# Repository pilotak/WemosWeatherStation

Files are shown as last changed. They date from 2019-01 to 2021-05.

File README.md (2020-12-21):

# Wemos weather station
 


An all-in-one ESP8266 based weather station. Hardware configuration is split into two parts due to easier maintenance in case of ESP8266 failure and fuse replacement (the board outside is protected against lighting). FW can easily be compiled by PlatformIO or Arduino IDE if necessary, otherwise can be downloaded in **Releases**.

Data are sent over MQTT where [Telegraf](https://www.influxdata.com/time-series-platform/telegraf/) is waiting to push data to [InfluxDB](https://www.influxdata.com/time-series-platform/influxdb/) and [Grafana](https://grafana.com/) tool to render charts.

**Main futures:**
- Easy configuration via [WiFiManager](https://github.com/tzapu/WiFiManager)
- WeMos based shield
- WH1080 mechanical components for rain, wind measurements and radiation shield
- MCP9808: high precision temperature sensor
- HTU21D or SHT31D: humidity sensor
- BMP280 or LPS35HW: pressure sensor
- Output data is via MQTT
- supports Arduino OTA, HTTP OTA and [NoFuss OTA](https://github.com/xoseperez/espurna)

*Note: on the board there can be only one humidity sensor, one pressure sensor and one temperature sensor in any combination, please see `platformio.ini`*

## Wemos-meteo shield
Based on my libraries:
- [WeatherMeters](https://github.com/pilotak/WeatherMeters)
- [MeteoFunctions](https://github.com/pilotak/MeteoFunctions)

### MQTT topics:
#### `name/status`
If online:
`sensors` key: binary map of sensors state (OK=1, failure=0)
```json
{
  "status": 1,
  "ip": "192.168.1.7",
  "rssi": -10,
  "sensors": 7,
  "fw_ver": "1.0.0"
}
```

otherwise:
```json
{
  "status": 0
}
```

#### `name/sensors`
If any of the value can't be calculated, it sends `NaN`
```json
{
  "humidity_rel": 79.84,
  "humidity_abs": 14.93,
  "pressure_rel": 1021.85,
  "pressure_abs": 967.55,
  "dew": 2.13,
  "humidex": 3.69,
  "heat": 3.97,
  "cloud": 390.13,
  "temp": [
    5.32,
    5.36,
    5.43
  ]
}
```

#### `name/upgrade`
As a data send link to `*.bin` upgrade package and it will reply in topic `name/upgrade/status`
(HTTP support only) *ie.: `http://somewebsite.com/upload/package.bin`*

#### `name/height`
As a data send new height and it will confirm in topic `name/height/new`

<table border="0">
 <tr>
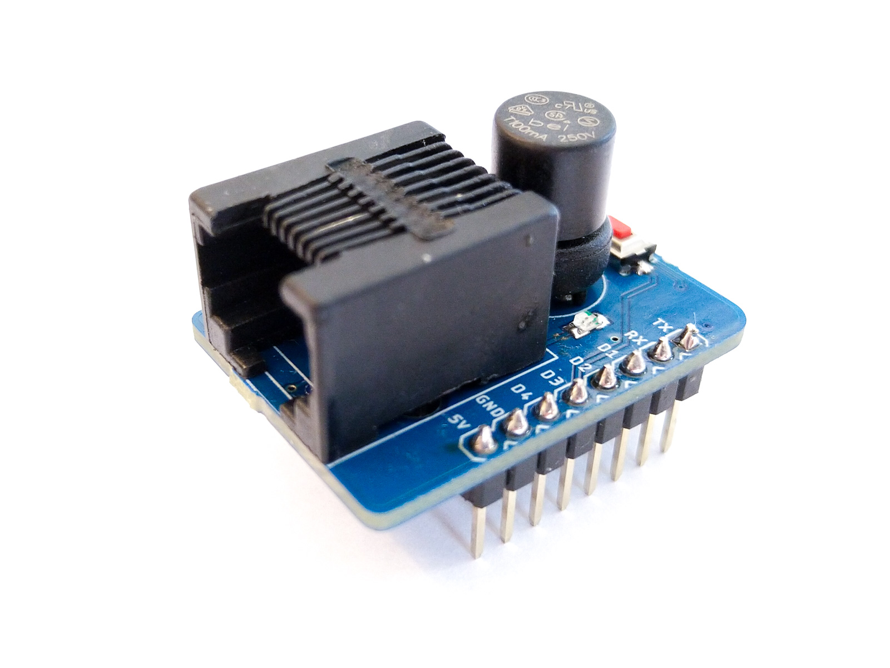
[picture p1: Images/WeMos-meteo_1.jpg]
Wemos meteo 1
    <td></td>
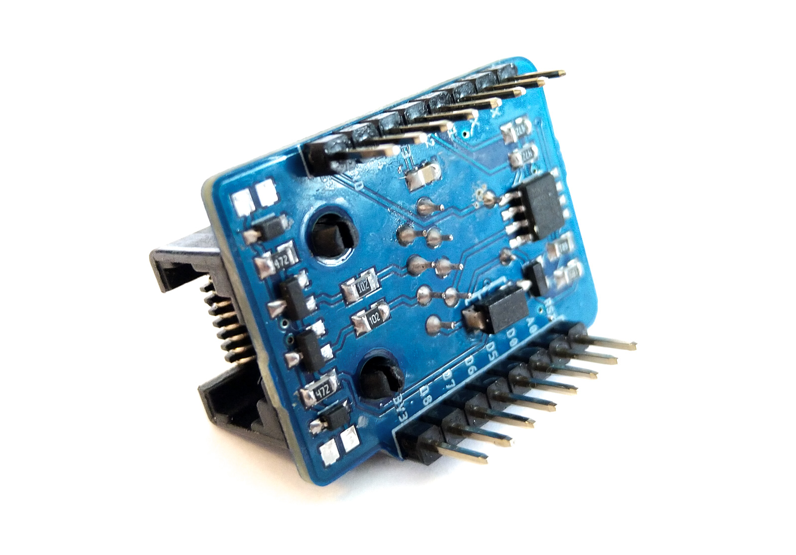
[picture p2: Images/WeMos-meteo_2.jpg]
Wemos meteo 2
    <td></td>
 </tr>
</table>

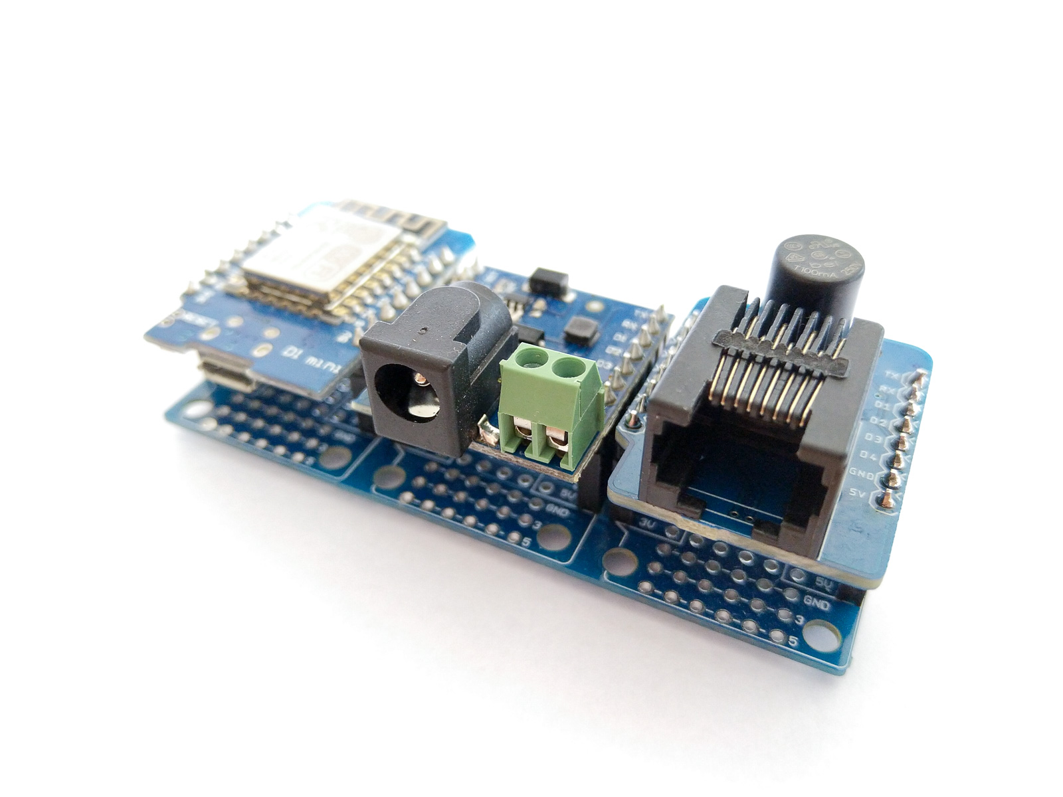
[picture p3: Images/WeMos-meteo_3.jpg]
Wemos meteo 3


## Weather board
Fits directly into radiation shield, just connect wind sensors, rain gauge bucket and you ready to measure. For future i have included extention connector for measuring sun light and UV index.

**_Update, I have created a sencond version of WeatherBoard with water-proof sensors SHT31D and LPS35HW but be carefull they are difficult to solder due to its size._**

<table border="0">
 <tr>
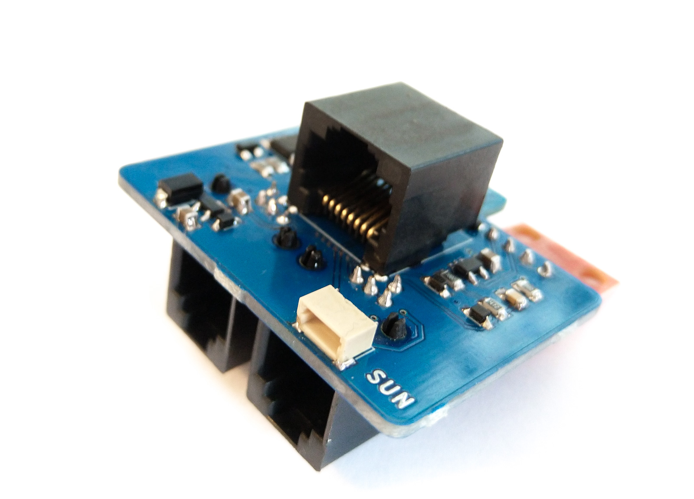
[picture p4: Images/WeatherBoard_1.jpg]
WeatherBoard 1
    <td></td>
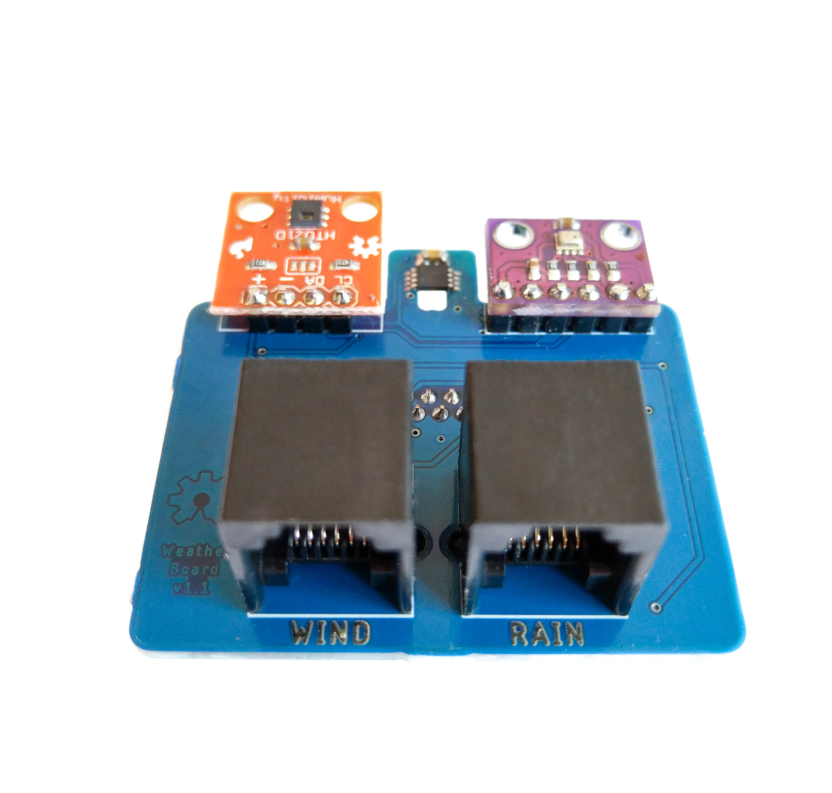
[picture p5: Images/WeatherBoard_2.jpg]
WeatherBoard 2
    <td></td>
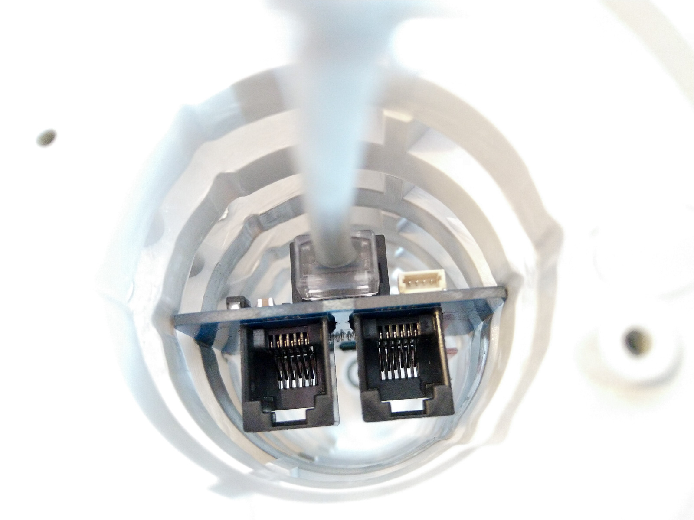
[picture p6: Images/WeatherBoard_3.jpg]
WeatherBoard 3
    <td></td>
 </tr>
 <tr>
    <td></td>
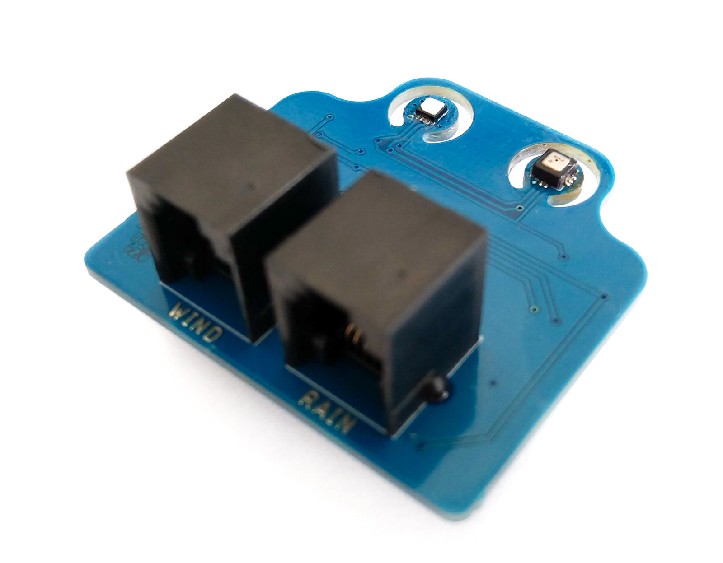
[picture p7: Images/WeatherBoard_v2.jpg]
WeatherBoard V2
    <td></td>
    <td></td>
 </tr>
</table>

## Server configuration
Below you can find a `docker-compose.yaml` file for fast integration onto your server.
```yaml
version: "3.6"

services:
  mosquitto:
    container_name: mosquitto
    restart: always
    image: eclipse-mosquitto
    ports:
      - 1883:1883
    volumes:
      - ${DOCKER_PATH}/mosquitto/mosquitto.conf:/mosquitto/config/mosquitto.conf
      - ${DOCKER_PATH}/mosquitto/pwfile:/mosquitto/config/pwfile
      - ${DOCKER_PATH}/mosquitto/data:/mosquitto/data

  influxdb:
    container_name: influxdb
    restart: always
    image: influxdb:alpine
    environment:
      - INFLUXDB_REPORTING_DISABLED=true
      - INFLUXDB_DB=${INFLUX_DB}
      - INFLUXDB_ADMIN_USER=${INFLUX_ADMIN_USER}
      - INFLUXDB_ADMIN_PASSWORD=${INFLUX_ADMIN_PASSWORD}
      - INFLUXDB_USER=${INFLUX_USER}
      - INFLUXDB_USER_PASSWORD=${INFLUX_PASSWORD}
      - INFLUXDB_READ_USER=${INFLUX_READ_USER}
      - INFLUXDB_READ_USER_PASSWORD=${INFLUX_READ_PASSWORD}
      - INFLUXDB_WRITE_USER=${INFLUX_WRITE_USER}
      - INFLUXDB_WRITE_USER_PASSWORD=${INFLUX_WRITE_PASSWORD}
      - INFLUXDB_HTTP_AUTH_ENABLED=true
    volumes:
      - ${DOCKER_PATH}/influxdb:/var/lib/influxdb
    ports:
      - 8086:8086

  grafana:
    container_name: grafana
    restart: always
    image: grafana/grafana
    depends_on:
      - influxdb
    environment:
      - GF_ANALYTICS_REPORTING_ENABLED=false
      - GF_ANALYTICS_CHECK_FOR_UPDATES=false
      - GF_SECURITY_DISABLE_GRAVATAR=true
      - GF_SNAPSHOTS_EXTERNAL_ENABLED=false
      - GF_AUTH_ANONYMOUS_ENABLED=true
      - GF_AUTH_ANONYMOUS_ORG_NAME=${INFLUX_DB}
      - GF_AUTH_ANONYMOUS_ORG_ROLE=Viewer
      - GF_AUTH_DISABLE_SIGNOUT_MENU=true
      - GF_AUTH_BASIC_ENABLED=false
      - GF_SERVER_ROOT_URL=https://meteo.${MY_DOMAIN}
    volumes:
      - ${DOCKER_PATH}/grafana:/var/lib/grafana
    ports:
      - 3000:3000

  telegraf_meteo:
    container_name: telegraf_meteo
    restart: always
    image: telegraf:alpine
    depends_on:
      - influxdb
      - mosquitto
    volumes:
      - ${DOCKER_PATH}/telegraf/meteo.conf:/etc/telegraf/telegraf.conf:ro

```

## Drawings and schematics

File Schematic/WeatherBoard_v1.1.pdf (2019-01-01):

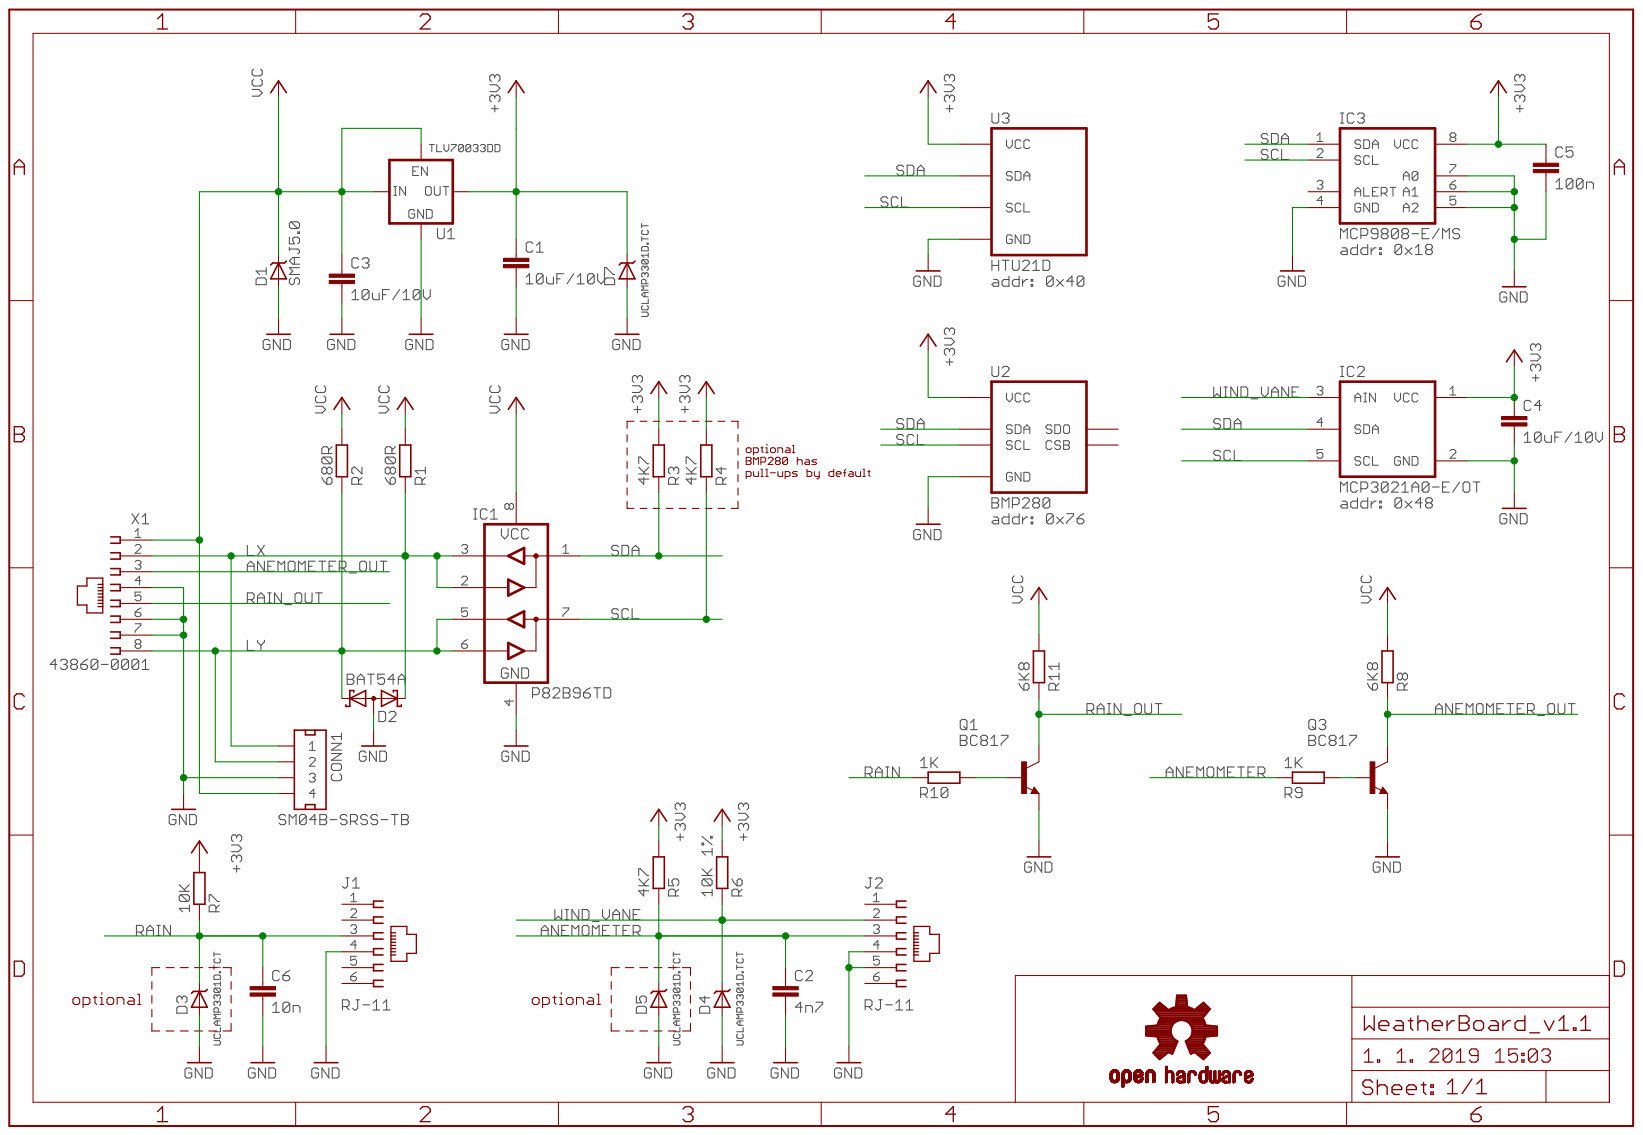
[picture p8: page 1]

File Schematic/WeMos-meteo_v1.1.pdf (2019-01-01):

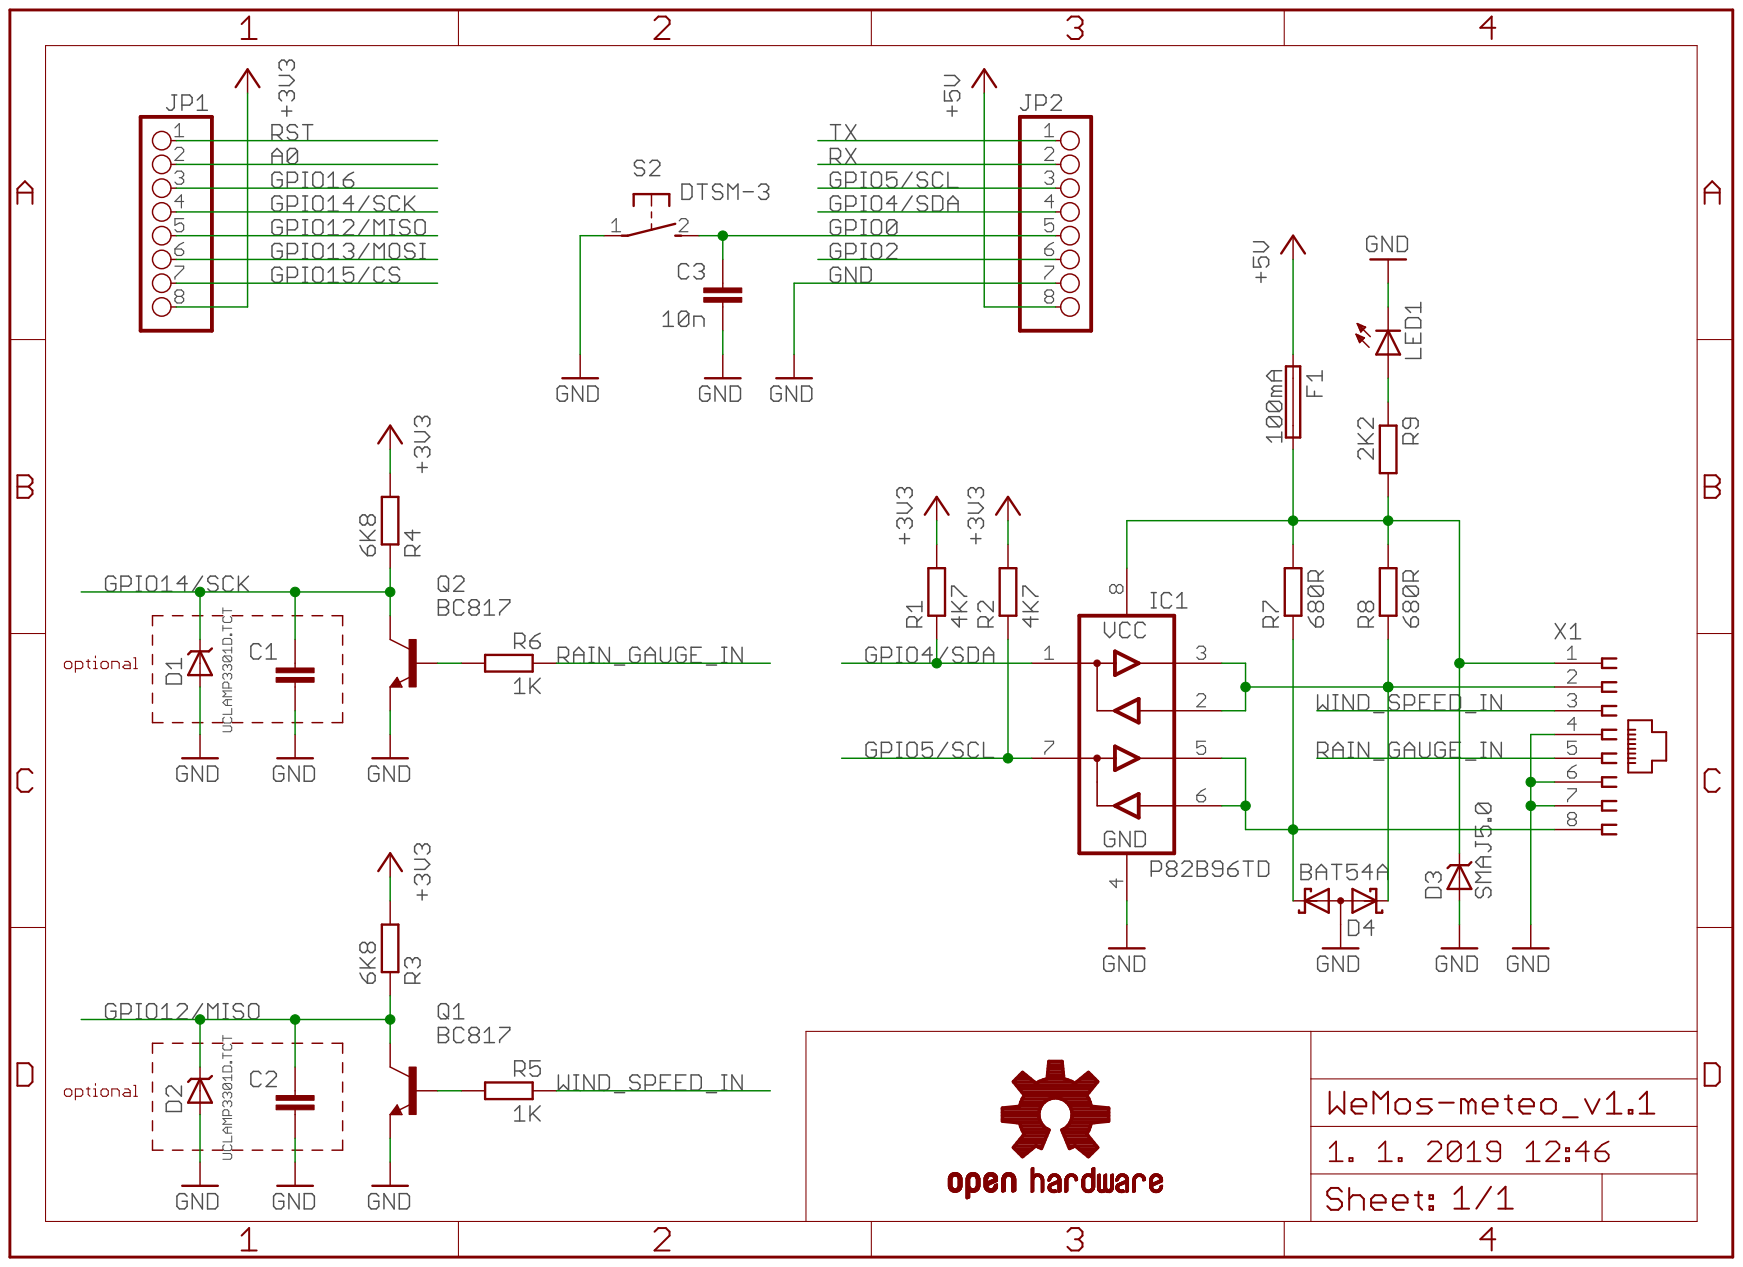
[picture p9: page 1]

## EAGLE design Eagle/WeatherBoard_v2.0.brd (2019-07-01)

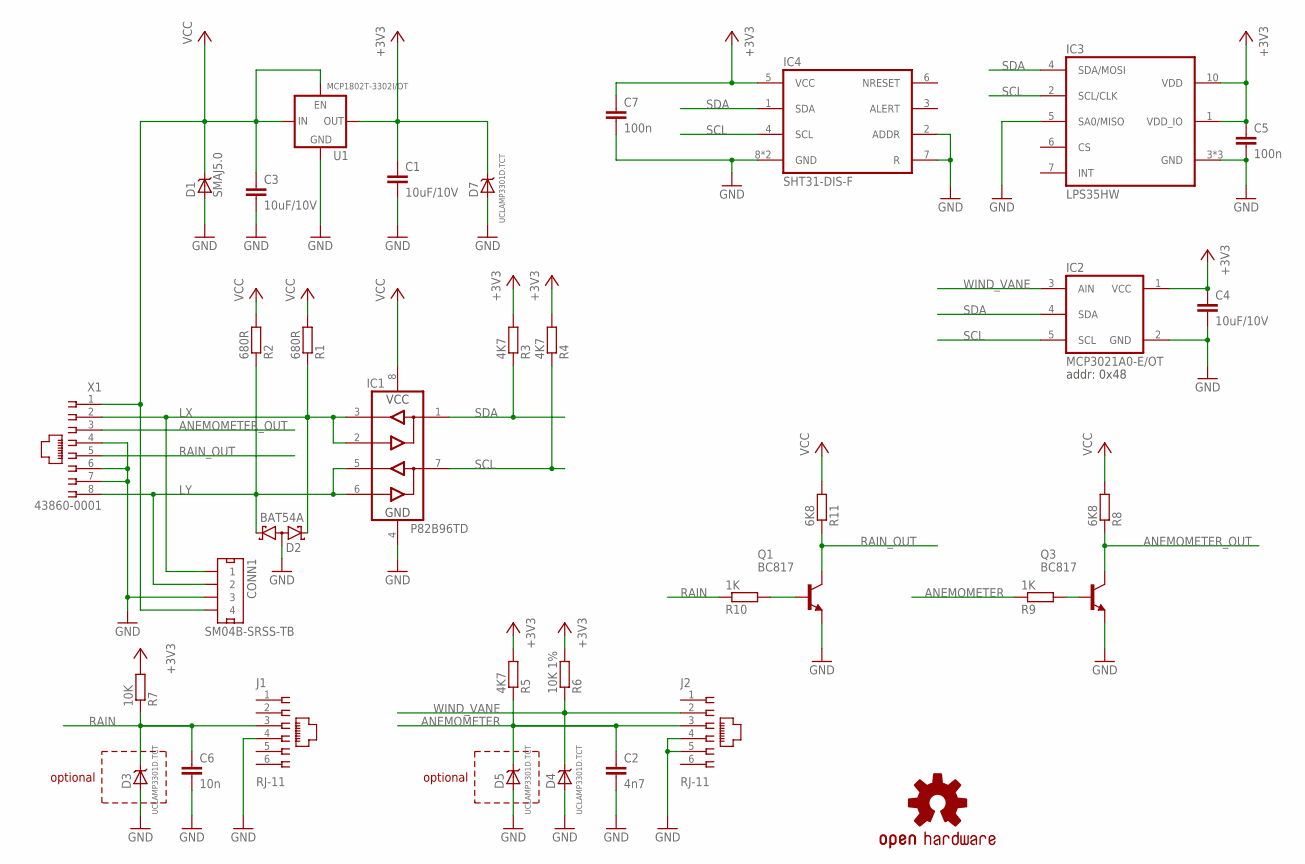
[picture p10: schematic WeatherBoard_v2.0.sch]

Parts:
C1, C3, C4: 10uF/10V; C0805
C2: 4n7; C0805
C5, C7: 100n; C0805
C6: 10n; C0805
CONN1: SM04B-SRSS-TB; JST-SRSS-4-T
D1: SMAJ5.0; DO214AC
D2: BAT54A; SOT23
D3, D4, D5, D7: UCLAMP3301D.TCT; SOD323
IC1: P82B96TD; SO08
IC2: MCP3021A0-E/OT; SOT23-5
IC3: LPS35HW; CCLGA10L
IC4: SHT31-DIS-F; DFN8
J1, J2: RJ-11; 615006138421
LOGO1: OSHW-LOGOM-COPPER; OSHW-LOGO-M_COPPER
Q1, Q3: BC817; SOT23-BEC
R1, R2: 680R; R0805
R3, R4, R5: 4K7; R0805
R6: 10K 1%; R0805
R7: 10K; R0805
R8, R11: 6K8; R0805
R9, R10: 1K; R0805
U1: MCP1802T-3302I/OT; SOT23-5
X1: 43860-0001; MX-43860-0001

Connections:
+3V3: C1.1, C4.1, C5.1, C7.1, D7.C, IC2.1 (VCC), IC3.1 (VDD_IO), IC3.10 (VDD), IC4.5 (VCC), R3.2, R4.2, R5.2, R6.2, R7.2, U1.5 (VOUT)
ANEMOMETER: C2.1, D5.C, J2.3, R5.1, R9.1
ANEMOMETER_OUT: Q3.C, R8.1, X1.3
GND: C1.2, C2.2, C3.2, C4.2, C5.2, C6.2, C7.2, CONN1.3, D1.A, D2.3 (AA), D3.A, D4.A, D5.A, D7.A, IC1.4 (GND), IC2.2 (GND), IC3.3 (GND), IC3.5 (SA0/MISO), IC3.8 (GND), IC3.9 (GND), IC4.2 (ADDR), IC4.7 (R), IC4.8 (GND), IC4.PAD (GND), J1.4, J2.4, J2.5, Q1.E, Q3.E, U1.2 (GND), X1.4, X1.6, X1.7
LX: CONN1.1, D2.2 (K2), IC1.2 (RX), IC1.3 (TX), R1.1, X1.2
LY: CONN1.2, D2.1 (K1), IC1.5 (TY), IC1.6 (RY), R2.1, X1.8
unnamed: Q3.B, R9.2
unnamed: Q1.B, R10.2
RAIN: C6.1, D3.C, J1.3, R7.1, R10.1
RAIN_OUT: Q1.C, R11.1, X1.5
SCL: IC1.7 (SY), IC2.5 (SCL), IC3.2 (SCL/CLK), IC4.4 (SCL), R4.1
SDA: IC1.1 (SX), IC2.4 (SDA), IC3.4 (SDA/MOSI), IC4.1 (SDA), R3.1
VCC: C3.1, CONN1.4, D1.C, IC1.8 (VCC), R1.2, R2.2, R8.2, R11.2, U1.1 (VIN), U1.3 (EN), X1.1
WIND_VANE: D4.C, IC2.3 (AIN), J2.2, R6.1

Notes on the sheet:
addr: 0x48
optional

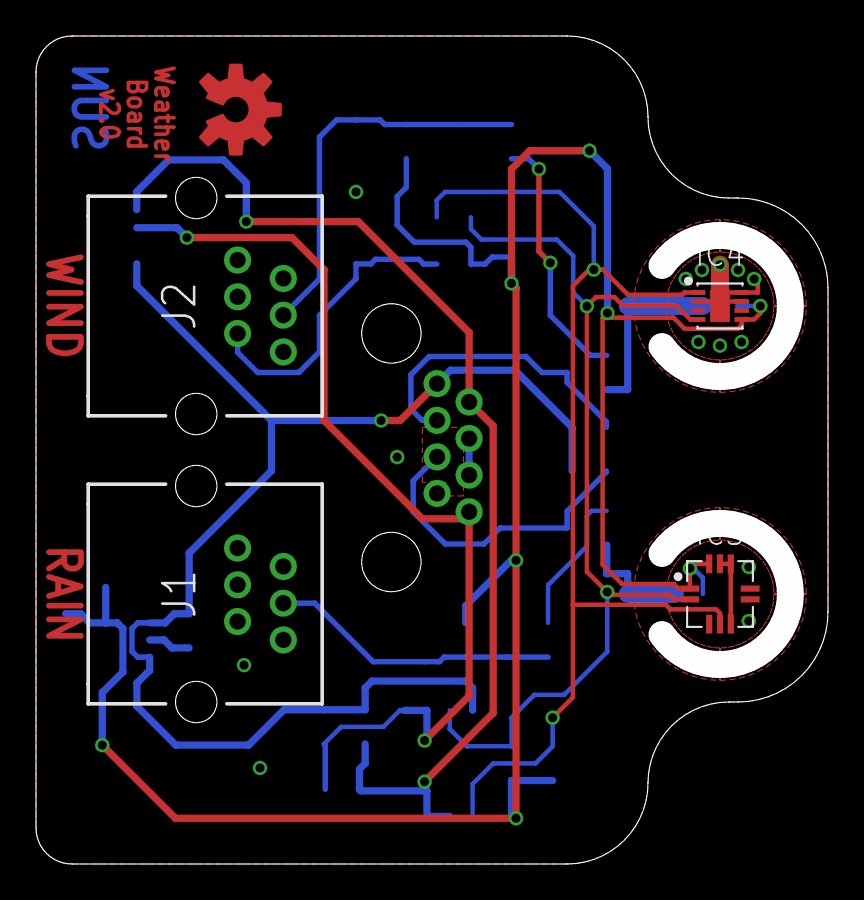
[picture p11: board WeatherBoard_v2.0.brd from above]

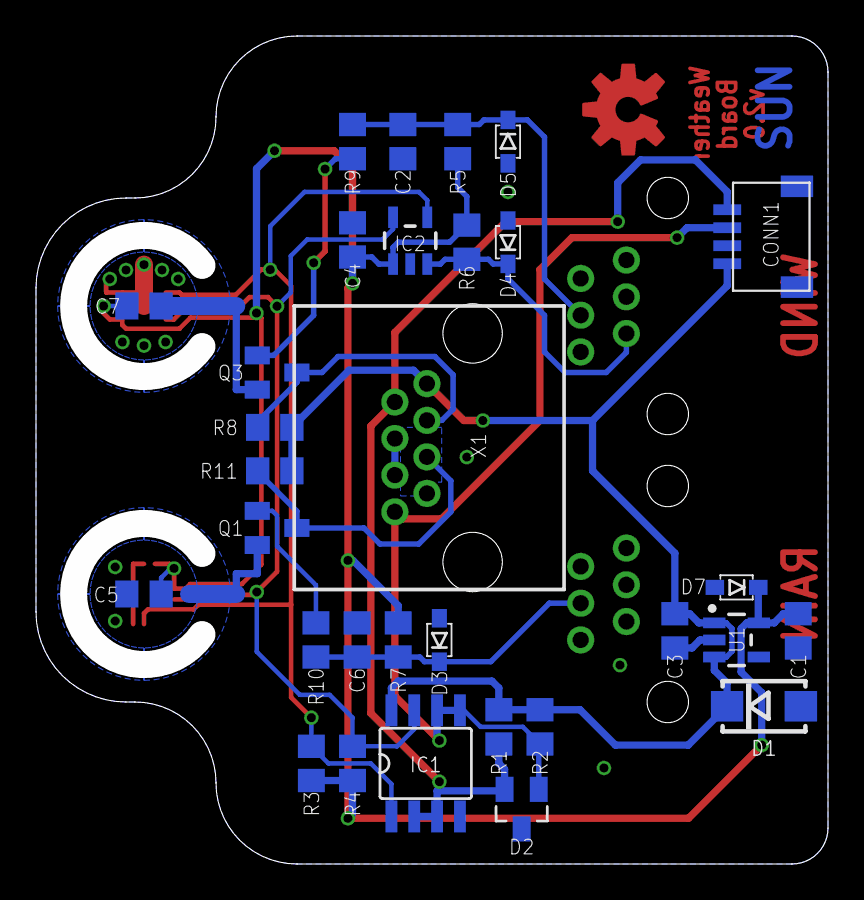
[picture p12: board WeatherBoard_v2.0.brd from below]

Board: 2 copper layers, 44.0 x 46.0 mm, 36 parts (31 on the bottom side), 14 nets.

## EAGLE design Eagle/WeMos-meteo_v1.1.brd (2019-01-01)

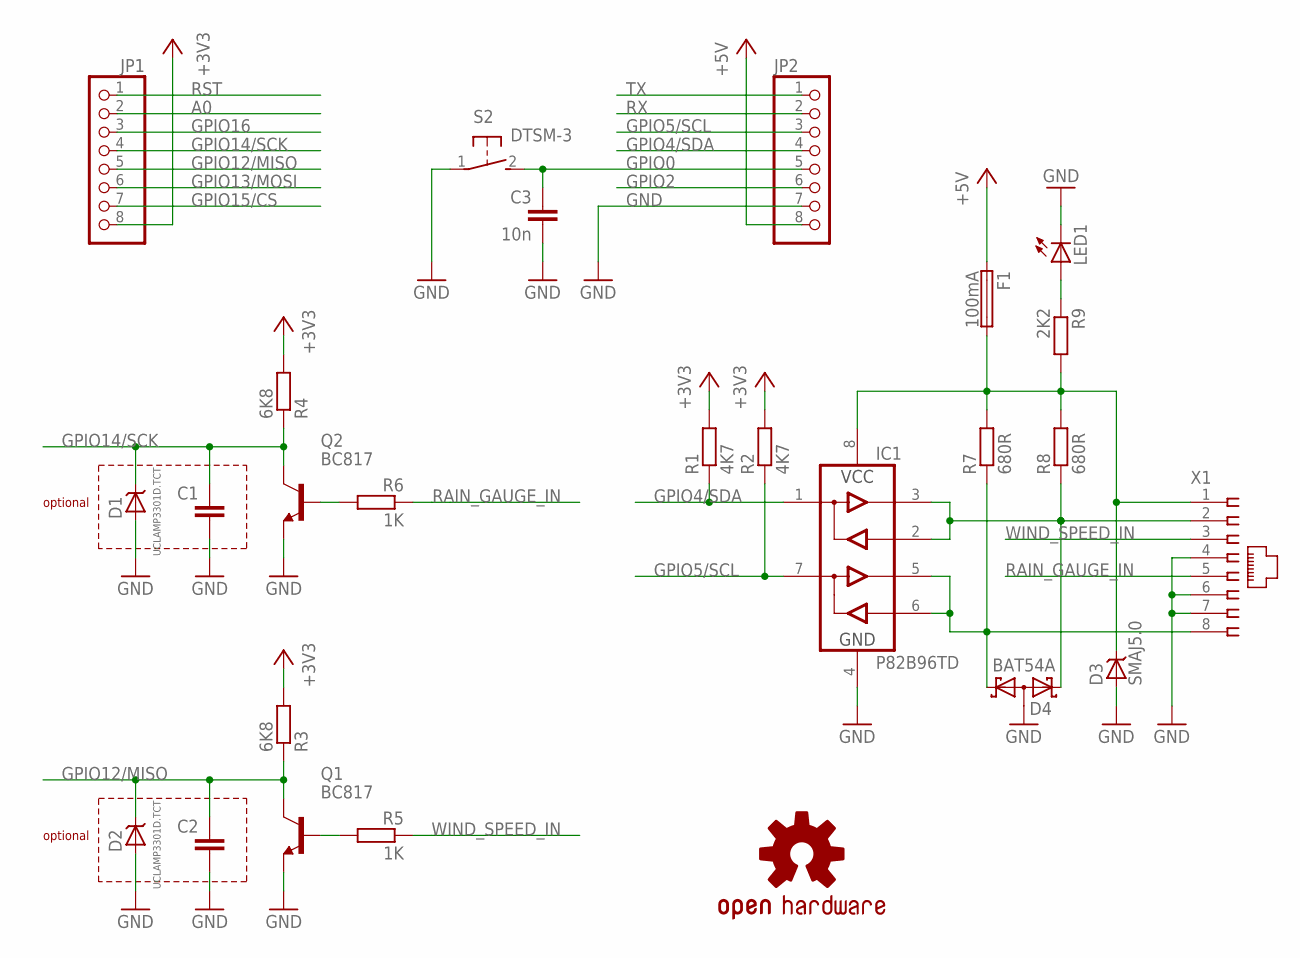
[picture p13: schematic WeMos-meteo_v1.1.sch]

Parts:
C1, C2: C-EUC0805; C0805
C3: 10n; C0805
D1, D2: UCLAMP3301D.TCT; SOD323
D3: SMAJ5.0; DO214AC
D4: BAT54A; SOT23
F1: 100mA; 19560
IC1: P82B96TD; SO08
JP1, JP2: PINHD-1X08_2.54-S; 1X08-S
LED1: LED0805
LOGO1: OSHW-LOGOMINI; OSHW-LOGO-MINI
Q1, Q2: BC817; SOT23-BEC
R1, R2: 4K7; R0805
R3, R4: 6K8; R0805
R5, R6: 1K; R0805
R7, R8: 680R; R0805
R9: 2K2; R0805
S2: DTSM-3
X1: RJ-45; 95501

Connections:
+3V3: JP1.8, R1.2, R2.2, R3.2, R4.2
+5V: F1.1, JP2.8
A0: JP1.2
GND: C1.2, C2.2, C3.2, D1.A, D2.A, D3.A, D4.3 (AA), IC1.4 (GND), JP2.7, LED1.C, Q1.E, Q2.E, S2.1, X1.4, X1.6, X1.7
GPIO0: C3.1, JP2.5, S2.2
GPIO2: JP2.6
GPIO4/SDA: IC1.1 (SX), JP2.4, R1.1
GPIO5/SCL: IC1.7 (SY), JP2.3, R2.1
GPIO12/MISO: C2.1, D2.C, JP1.5, Q1.C, R3.1
GPIO13/MOSI: JP1.6
GPIO14/SCK: C1.1, D1.C, JP1.4, Q2.C, R4.1
GPIO15/CS: JP1.7
GPIO16: JP1.3
unnamed: D4.2 (K2), IC1.2 (RX), IC1.3 (TX), R8.1, X1.2
unnamed: D4.1 (K1), IC1.5 (TY), IC1.6 (RY), R7.1, X1.8
unnamed: Q1.B, R5.2
unnamed: Q2.B, R6.2
unnamed: LED1.A, R9.1
RAIN_GAUGE_IN: R6.1, X1.5
RST: JP1.1
RX: JP2.2
TX: JP2.1
VCC: D3.C, F1.2, IC1.8 (VCC), R7.2, R8.2, R9.2, X1.1
WIND_SPEED_IN: R5.1, X1.3

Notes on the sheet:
optional

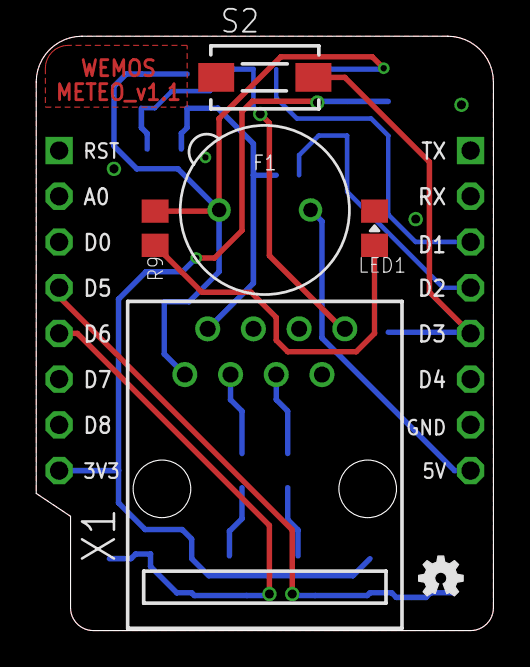
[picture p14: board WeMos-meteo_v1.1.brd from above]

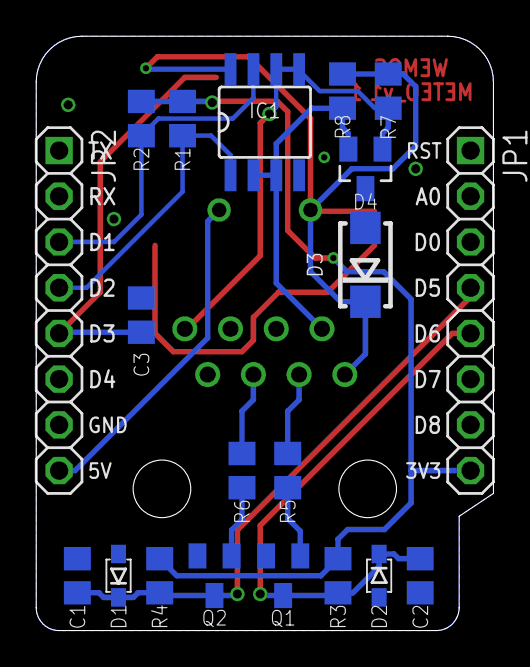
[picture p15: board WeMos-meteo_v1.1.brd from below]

Board: 2 copper layers, 25.4 x 33.0 mm, 26 parts (20 on the bottom side), 16 nets.

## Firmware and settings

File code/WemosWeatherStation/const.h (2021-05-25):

#define DEVICE_NAME "meteo"  // used for MQTT, OTA, AP
#define FW_VERSION "2.0.0"

#define CONFIG_PATH "/config.json"
#define CONFIG_AP_SSID DEVICE_NAME "_config"
#define CONFIG_AP_PASSWORD "StrongPasswordHere"
#define CONFIG_PORTAL_TIMEOUT 120  // sec

#define DEFAULT_MQTT_PORT 1883
#define MQTT_QOS 1
#define MQTT_RETAIN true
#define MQTT_CHECK_INTERVAL 5000
#define MQTT_STATUS_INTERVAL 30000
#define MQTT_STATUS_TOPIC DEVICE_NAME "/status"  // will result ie. meteo/status
#define MQTT_UPGRADE_TOPIC DEVICE_NAME "/upgrade"  // will result ie. meteo/upgrade
#define MQTT_UPGRADE_STATUS_TOPIC DEVICE_NAME "/upgrade/status"  // will result ie. meteo/upgrade/status
#define MQTT_RESTART_TOPIC DEVICE_NAME "/restart"  // will result ie. meteo/restart
#define MQTT_HEIGHT_UPDATE_TOPIC DEVICE_NAME "/height"  // will result ie. meteo/height
#define MQTT_HEIGHT_NEW_TOPIC MQTT_HEIGHT_UPDATE_TOPIC "/new"  // will result ie. meteo/height/new
#define MQTT_SENSORS_TOPIC DEVICE_NAME "/sensors"  // will result ie. meteo/sensors
#define MQTT_WIND_TOPIC DEVICE_NAME "/wind"  // will result ie. meteo/wind
#define MQTT_RAIN_TOPIC DEVICE_NAME "/rain"  // will result ie. meteo/rain
#define MQTT_STATUS_ALIVE 1
#define MQTT_STATUS_DEAD 0

#define BUTTON_PIN D3
#define LONG_PRESS 1000  // ms

#define READ_INTERVAL 3750  // ms
#define READ_SAMPLES 16  // READ_INTERVAL*SAMPLES=sending time of sensors in ms
#define METERS_INTERVAL 60  // how ofter send data from meters in sec
#define METERS_DIR_FILTERING 16  // filter last 16 samples of wind vane
#define DEFAULT_HEIGHT_ABOVE_SEA 415  // m

#define I2C_SPEED 100000
#define BMP280_ADDR BME280I2C::I2CAddr_0x76  // or BME280I2C::I2CAddr_0x77
#define MCP9808_ADDR 0x18
#define HTU21D_ADDR 0x40
#define SHT31D_ADDR 0x44
#define MCP3021_ADDRESS 0x48
#define ANEMOMETER_PIN D6
#define RAIN_GAUGE_PIN D5

#define NOFUSS_CHECK_INTERVAL 3600000  // 1h
#define OTA_PORT 8266  // for local updates

uint8_t sensor_state = 0b000;  // 0b(Humidity)(Temperature)(Barometer)

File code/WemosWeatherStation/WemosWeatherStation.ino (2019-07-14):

/*
MIT License
Copyright (c) 2019 Pavel Slama
Permission is hereby granted, free of charge, to any person obtaining a copy
of this software and associated documentation files (the "Software"), to deal
in the Software without restriction, including without limitation the rights
to use, copy, modify, merge, publish, distribute, sublicense, and/or sell
copies of the Software, and to permit persons to whom the Software is
furnished to do so, subject to the following conditions:
The above copyright notice and this permission notice shall be included in all
copies or substantial portions of the Software.
THE SOFTWARE IS PROVIDED "AS IS", WITHOUT WARRANTY OF ANY KIND, EXPRESS OR
IMPLIED, INCLUDING BUT NOT LIMITED TO THE WARRANTIES OF MERCHANTABILITY,
FITNESS FOR A PARTICULAR PURPOSE AND NONINFRINGEMENT. IN NO EVENT SHALL THE
AUTHORS OR COPYRIGHT HOLDERS BE LIABLE FOR ANY CLAIM, DAMAGES OR OTHER
LIABILITY, WHETHER IN AN ACTION OF CONTRACT, TORT OR OTHERWISE, ARISING FROM,
OUT OF OR IN CONNECTION WITH THE SOFTWARE OR THE USE OR OTHER DEALINGS IN THE
SOFTWARE.
*/

#include "const.h"
#include "load.h"
#include "wifi.h"
#include "mqtt.h"
#include "ota.h"
#include "button.h"
#include "sensors.h"

#if defined(HAS_METERS)
    #include "meters.h"
#endif

void setup() {
#if defined(DEBUG) || defined(DEBUG_ESP_PORT)
    Serial.begin(115200);
    Serial.println();
#endif

    if (loadDefaultConfig()) {
        buttonSetup();
        mqttSetup();
        wifiSetup();
        otaSetup();
        sensorsSetup();

#if defined(HAS_METERS)
        metersSetup();
#endif

    } else {
        while (1) {};
    }
}

void loop() {
    otaLoop();

    if (!ota_in_progess) {
        wifiManager.process();
        buttonLoop();

        if (WiFi.isConnected()) {
            mqttLoop();
            sensorsLoop();

#if defined(HAS_METERS)
            metersLoop();
#endif
        }
    }

#if defined(HTTP_OTA)

    if (do_http_update) {
        do_http_update = false;
        httpUpdate();
    }

#endif
}

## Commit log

2018-09-27 interrupt stop on OTA + enable timer WM
2018-10-17 check if sensors are available
2018-10-25 height_above_sea to WiFiManager + fixes
    [const.h]
2018-10-26 button dep fix
2018-12-09 sensor counter fix + SAMPLES macro rename
    [const.h]
2018-12-09 http update rework + mqtt confirmation update
    [WemosWeatherStation.ino, const.h]
2018-12-09 new dir filtering
2019-01-01 src files
    [WeMos-meteo_v1.1.brd, WeMos-meteo_v1.1.sch, WeatherBoard_v1.1.brd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]
2019-01-01 readme + licence update
    [ci skip]
    [WemosWeatherStation.ino, const.h]
2019-01-13 specify sensors at build
2019-02-10 set default I2C speed
2019-06-14 prepare for different sensors
2019-06-23 support different sensors
2019-07-01 eagle files for V2.0
    [WeatherBoard_v2.0.brd, WeatherBoard_v2.0.sch]
2019-07-14 create config if doesn't exists + PIO 4.0 + delay after OTA
    [WemosWeatherStation.ino, const.h]
2021-05-25 split sensor code + LittleFS
2026-10-25 fix heap overflow blocking MQTT publish, hostname + MQTT client ID from DEVICE_NAME
    IntParameter::setValue() wrote "1883\0" into a 4-byte buffer, corrupting
    the heap; AsyncMqttClient then saw no free block and dropped every publish.
    Hostname is DEVICE_NAME with '_' replaced by '-' (underscores are invalid
    in hostnames), MQTT client ID is DEVICE_NAME.
2026-10-25 BMP280 normal mode, pin platform and BME280 library
    Forced mode in finitespace/BME280 reads before the conversion finishes,
    so every reading was one sample old.

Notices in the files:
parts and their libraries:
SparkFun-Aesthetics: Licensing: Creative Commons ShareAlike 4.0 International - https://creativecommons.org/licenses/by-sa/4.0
